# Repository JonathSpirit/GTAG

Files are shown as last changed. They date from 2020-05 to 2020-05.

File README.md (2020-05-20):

# GTAG

Copyright (C) 2020 Guillaume Guillet\
Licensed under CERN OHL v.1.2

<table border="0px">
<tr>
<td>
This documentation describes Open Hardware and is licensed under the CERN OHL v. 1.2.
</td>
</tr>
<tr>
<td>
You may redistribute and modify this documentation under the terms of the
CERN OHL v.1.2. (http://ohwr.org/cernohl). This documentation is distributed
WITHOUT ANY EXPRESS OR IMPLIED WARRANTY, INCLUDING OF
MERCHANTABILITY, SATISFACTORY QUALITY AND FITNESS FOR A
PARTICULAR PURPOSE. Please see the CERN OHL v.1.2 for applicable
conditions
</td>
</tr>
</table>

## Description
GTAG is a small adaptation card for the silicon-labs JTAG Debug adapter.
The utility is to not having to place the big 1x05 header connector and not solder any resistance for
small board conception.

Silicon-labs USB-Debug-Adapter : https://www.silabs.com/documents/public/user-guides/8-bit-USB-Debug-Adapter.pdf

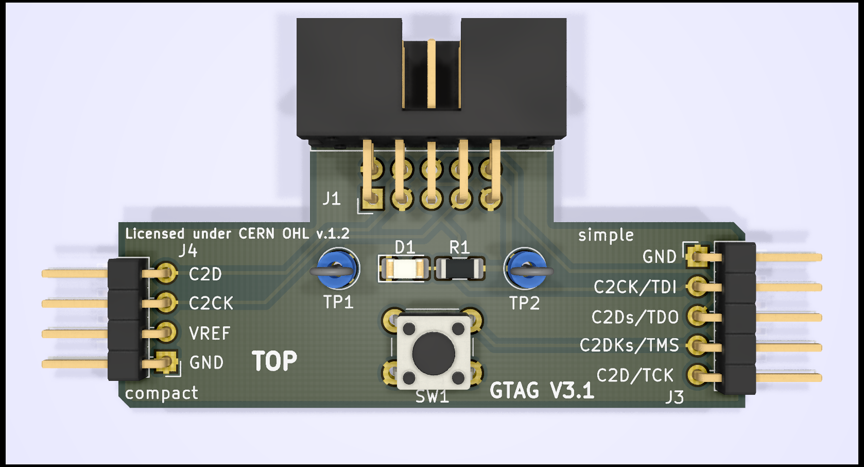
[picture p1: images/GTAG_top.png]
GTAG_image

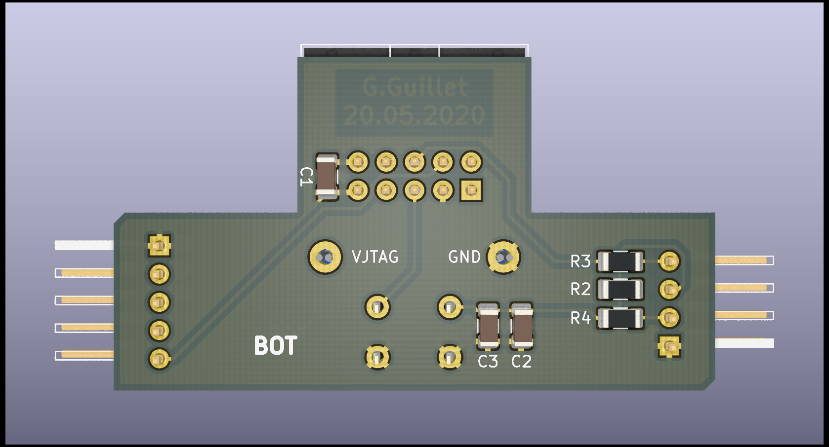
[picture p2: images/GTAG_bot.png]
GTAG_image


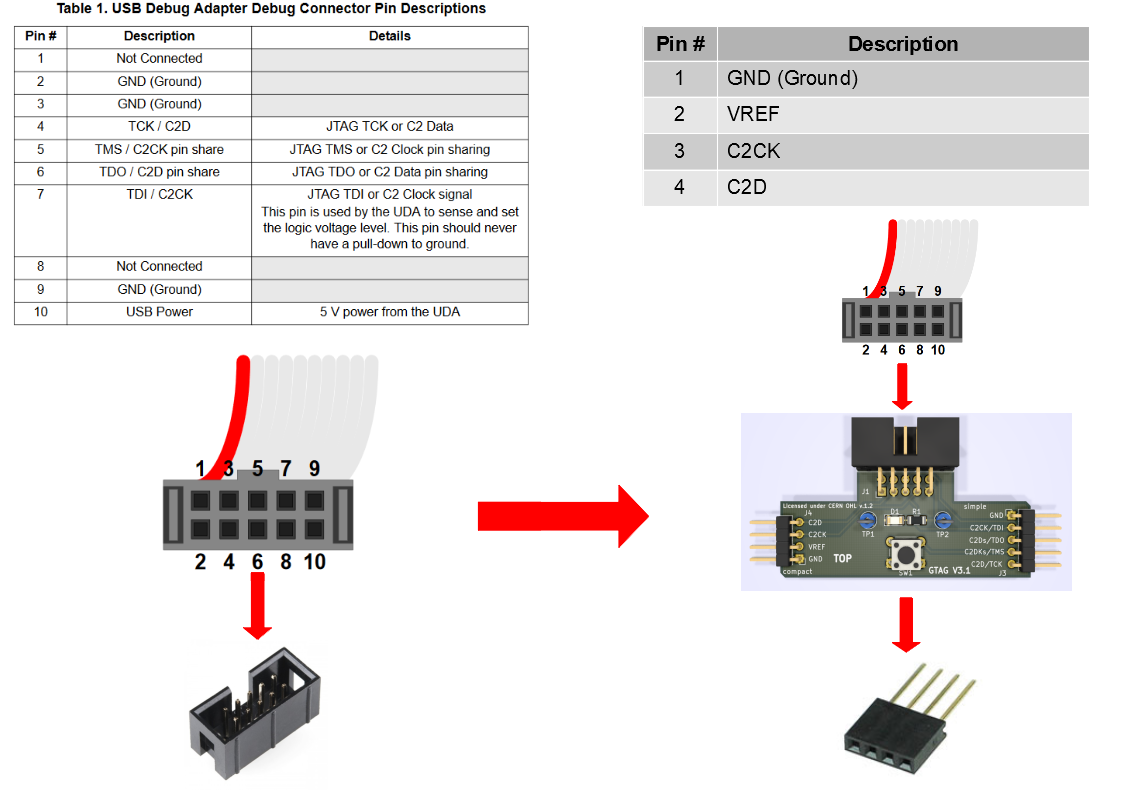
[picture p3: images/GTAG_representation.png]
GTAG_image


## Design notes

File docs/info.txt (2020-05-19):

Le GTAG est un adaptateur entre le uc et le JTAG de silicon labs.
GTAG is an adapter between the uc and the JTAG of silicon labs.

-------------------------------------------

R = 1k
between C2CKs_TMS and C2CK_TDI

R = 1k
between C2Ds_TDO and C2D_TCK

R = 1k
pull-up between VREF and C2CKs_TMS

-------------------------------------------

C2D_TCK to P3.0
C2CK_TDI to RST

from C8051F38x :
"an external pullup and/or decoupling of the RST
pin may be necessary to avoid erroneous noise-induced resets."

-------------------------------------------

Simple format  (5 pins) :

5) C2D_TCK
4) C2CKs_TMS
3) C2Ds_TDO
2) C2CK_TDI
1) GND

Compact format  (4 pins) :

4) C2D_TCK
3) C2CK_TDI
2) VREF
1) GND

-------------------------------------------

This documentation describes Open Hardware and is licensed under the
CERN OHL v. 1.2.

You may redistribute and modify this documentation under the terms of the
CERN OHL v.1.2. (http://ohwr.org/cernohl). This documentation is distributed
WITHOUT ANY EXPRESS OR IMPLIED WARRANTY, INCLUDING OF
MERCHANTABILITY, SATISFACTORY QUALITY AND FITNESS FOR A
PARTICULAR PURPOSE. Please see the CERN OHL v.1.2 for applicable
conditions

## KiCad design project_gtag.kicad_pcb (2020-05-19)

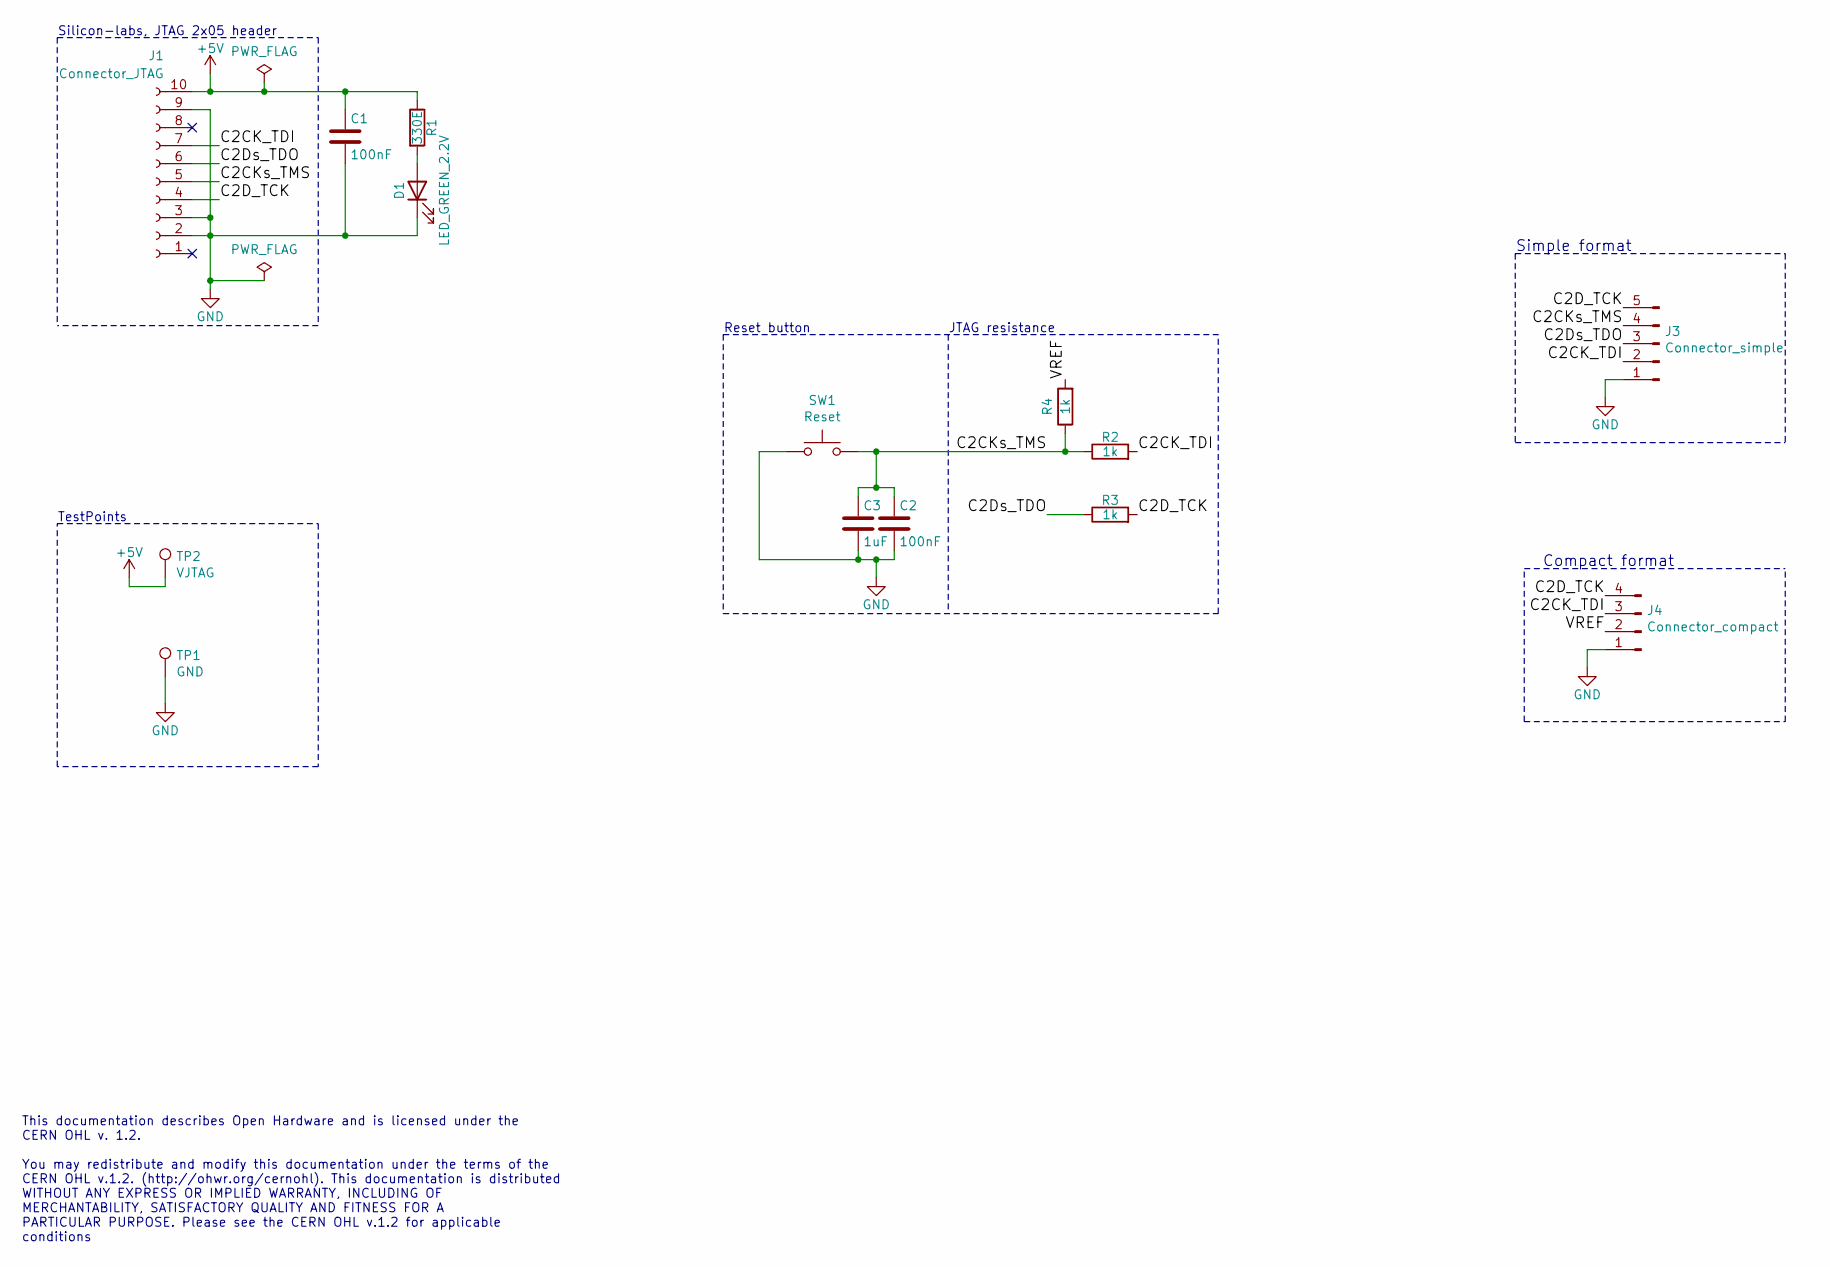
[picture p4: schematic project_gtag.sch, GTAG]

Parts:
C1, C2: 100nF; C_1206_3216Metric
C3: 1uF; C_1206_3216Metric
D1: LED_GREEN_2.2V; LED_1206_3216Metric
J1: Connector_JTAG; IDC-Header_2x05_P2.54mm_Horizontal
J3: Connector_simple; PinHeader_1x05_P2.54mm_Horizontal
J4: Connector_compact; PinHeader_1x04_P2.54mm_Horizontal
R1: 330E; R_1206_3216Metric
R2, R3, R4: 1k; R_1206_3216Metric
SW1: Reset; SW_PUSH_6mm
TP1: GND; TestPoint_Loop_D3.50mm_Drill1.4mm_Beaded
TP2: VJTAG; TestPoint_Loop_D3.50mm_Drill1.4mm_Beaded

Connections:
+5V: C1.1, J1.10, R1.1, TP2.1
/C2CK_TDI: J1.7, J3.2, J4.3, R2.2
/C2CKs_TMS: C2.1, C3.1, J1.5, J3.4, R2.1, R4.1, SW1.2
/C2D_TCK: J1.4, J3.5, J4.4, R3.2
/C2Ds_TDO: J1.6, J3.3, R3.1
/VREF: J4.2, R4.2
GND: C1.2, C2.2, C3.2, D1.1 (K), J1.2, J1.3, J1.9, J3.1, J4.1, SW1.1, TP1.1
unnamed: D1.2 (A), R1.2

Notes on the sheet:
Compact format
Simple format
Silicon-labs, JTAG 2x05 header
Reset button
JTAG resistance
TestPoints
This documentation describes Open Hardware and is licensed under the CERN OHL v. 1.2. You may redistribute and modify this documentation under the terms of the CERN OHL v.1.2. (http://ohwr.org/cernohl). This documentation is distributed WITHOUT ANY EXPRESS OR IMPLIED WARRANTY, INCLUDING OF MERCHANT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

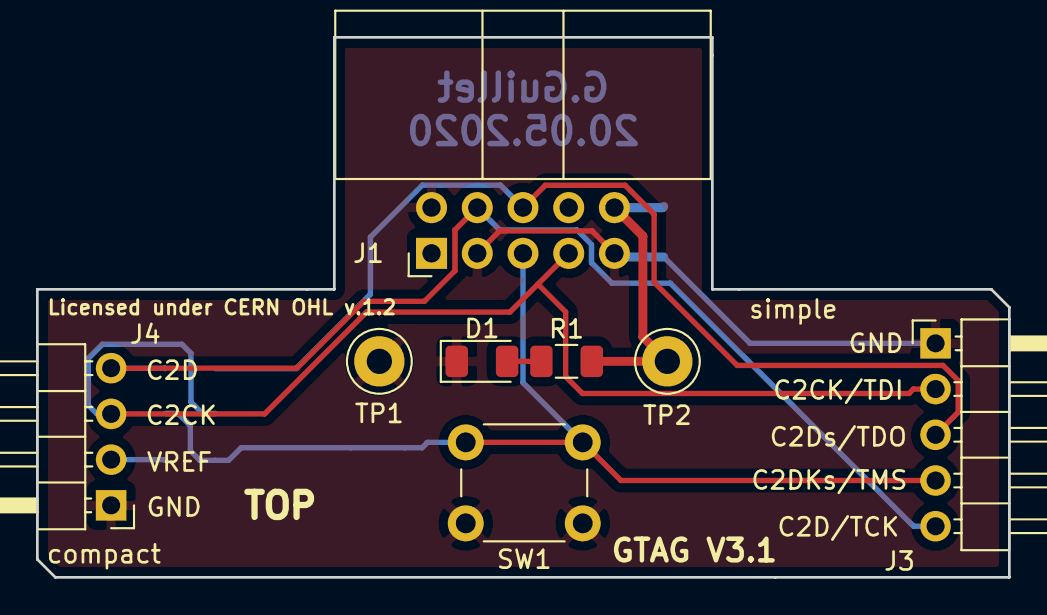
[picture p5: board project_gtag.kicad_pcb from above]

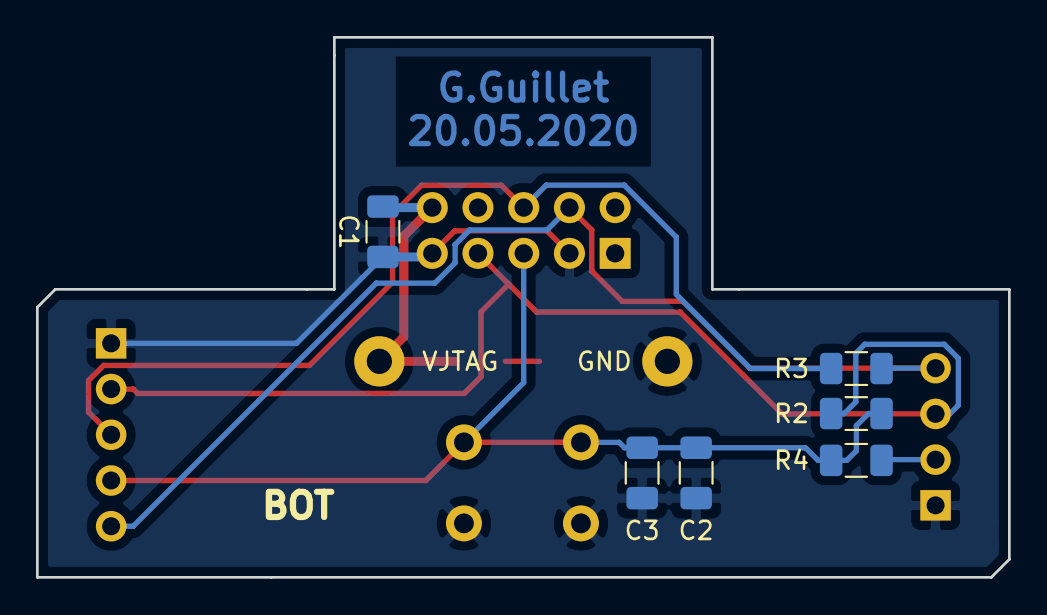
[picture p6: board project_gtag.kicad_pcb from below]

Board: 2 copper layers, 54.0 x 30.0 mm, 14 parts (6 on the bottom side), 8 nets.
